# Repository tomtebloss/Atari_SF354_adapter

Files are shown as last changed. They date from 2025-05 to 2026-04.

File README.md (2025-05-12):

<h1 align="center">
PCB for use in an Atari SF354/314 case.
</h1>

<h2 align="center">
Exchange original pcb to be able to read double sided floppy.

---

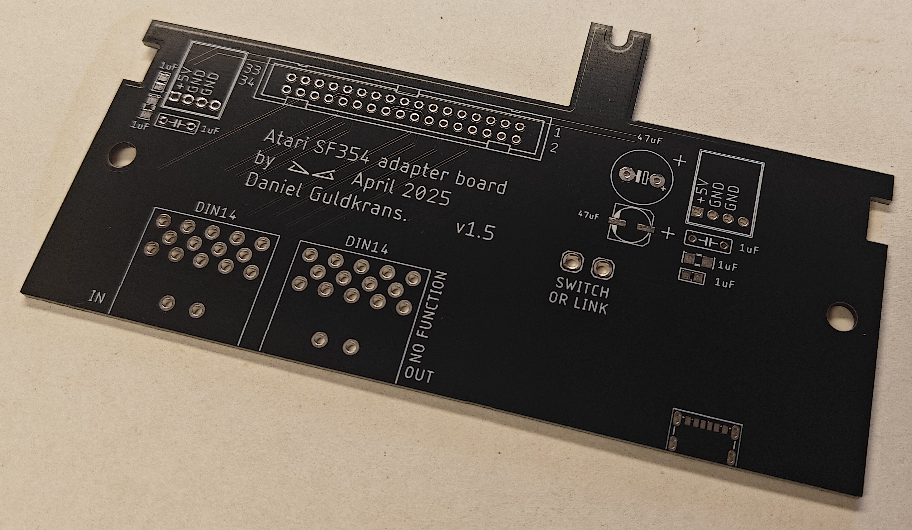
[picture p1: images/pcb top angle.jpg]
new pcb top

</h2>

---

## Background  

I bought an old SF354 case with a broken (dried belt) single sided floppy drive to convert to gotek. The case was the big eject button version. Apparently there is (at least) two different version of the pcb inside. One can be used with double sided drives without modifications. And one with a lot of components on the pcb that needs modifications to work with double sided drives (the one I got). I didn't get any signal cable or power cable/brick with my SF354 so it was no meaning to modify the old pcb since I had to source a power cable for it in that case. So I did a new PCB instead and used USB-C to power it. Only 5V. No 12V is used on this board. 

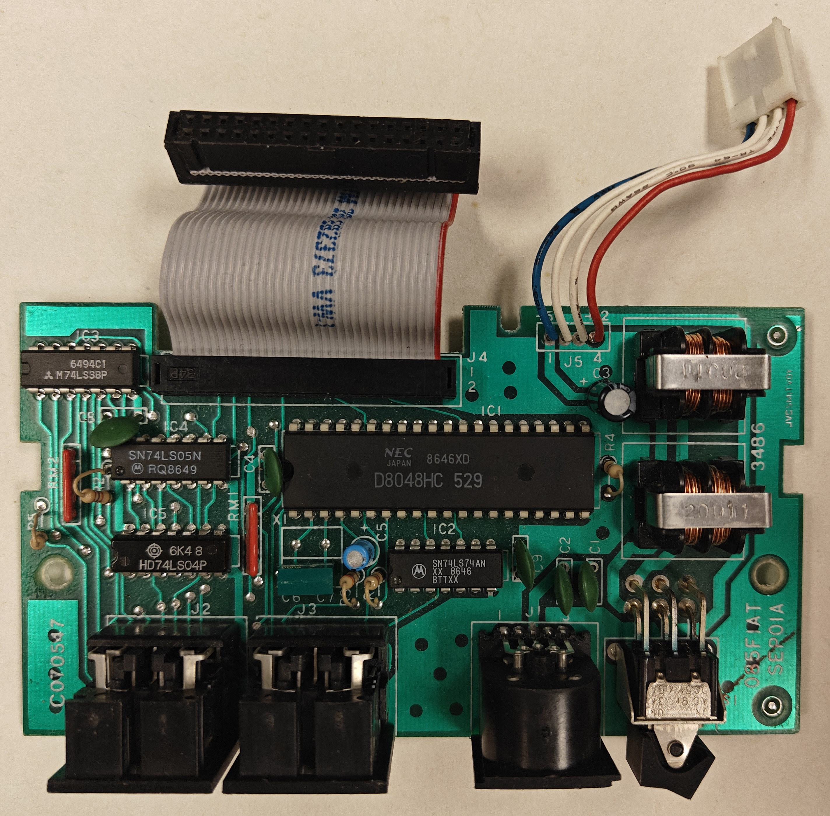
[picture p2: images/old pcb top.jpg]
SF354 original pcb top
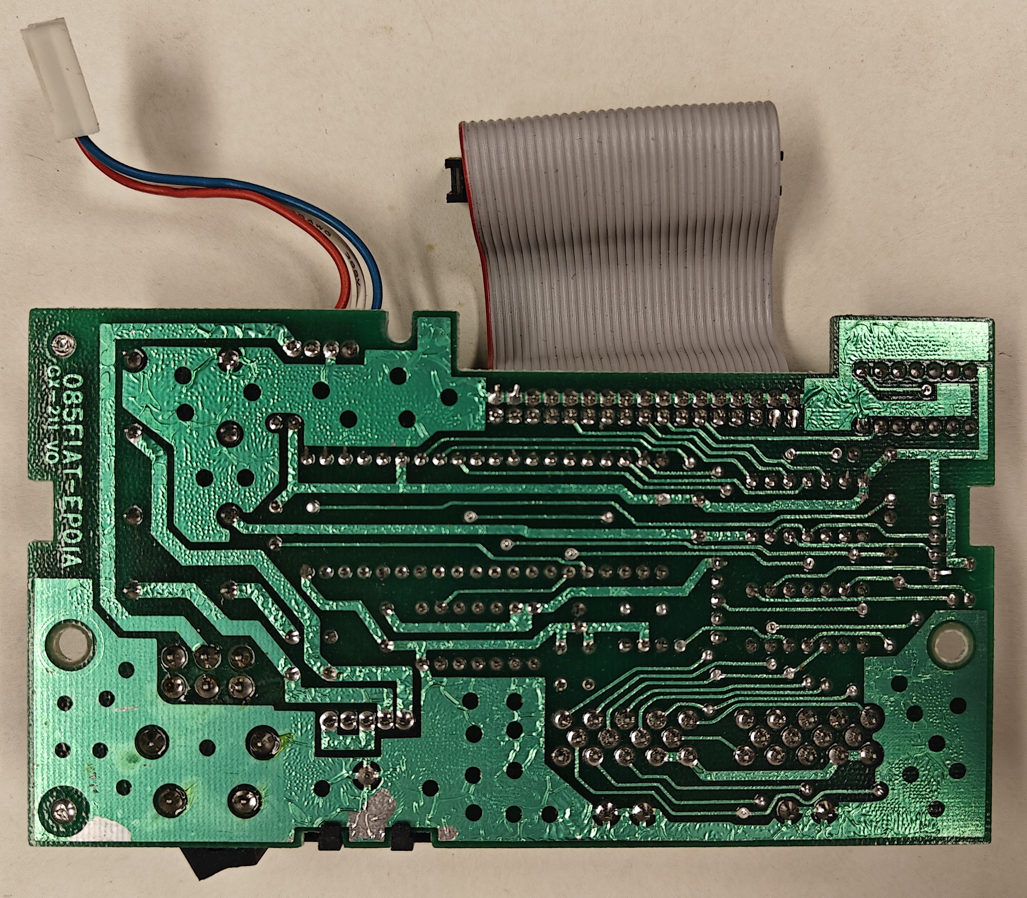
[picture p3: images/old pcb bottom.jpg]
SF354 original pcb bottom


---

## What you will need  

- One Adapter PCB. Order with the [gerber] file "SF354_adapter_pcb_gerber_v1.5.zip" from your favorite PCB manufactory. 
- 1 or 2 pcs of BERG 4 pin floppy power connector (or solder the wires directly to the pcb).
- 1 or 2 pcs of 100nF (0,1uF) 0805 SMD capacitors. This can bew omitted if you want.
- 1 or 2 pcs of 1uF capacitors. Either SMD (1206) or through hole (5,12mm leg pitch).
- One 47uF electrolytic capacitor. Either SMD (size C. 6,3x7,7mm) or through hole (5mm leg pitch).
- 2 pcs of 14 pin DIN connectors. Desolder from old pcb (only one is needed).
- One 34 pin IDC connector. (or solder the wires directly to the pcb).
- One USB-C 6 pin SMD connector. Only used for power.
- One switch (SPDT) or small piece of wire if you don't use it. 
- One Gotek drive or a real disk drive. If Gotek is used you must remove motor on jumper (MO). Only S0 should be jumpered.
- One 3D printed [bracket] for Gotek pcb. 

BOM/partlist can also be found in the [gerber] zip. There is also [PDF] for some parts.

---

## How to

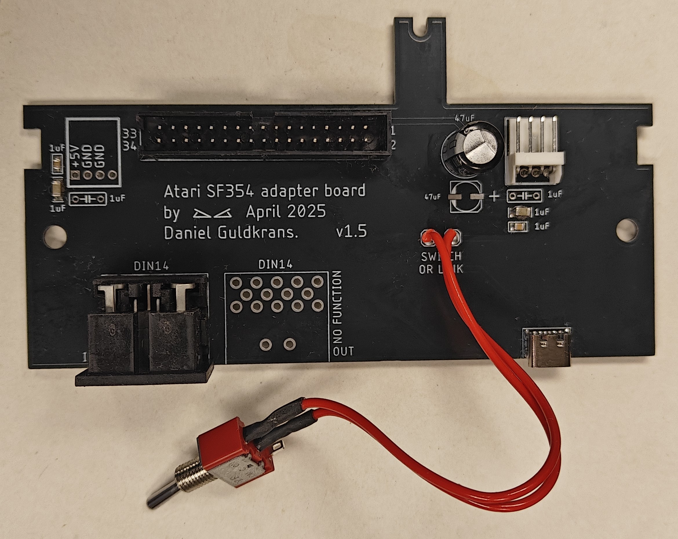
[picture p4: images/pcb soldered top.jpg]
pcb soldered - top side
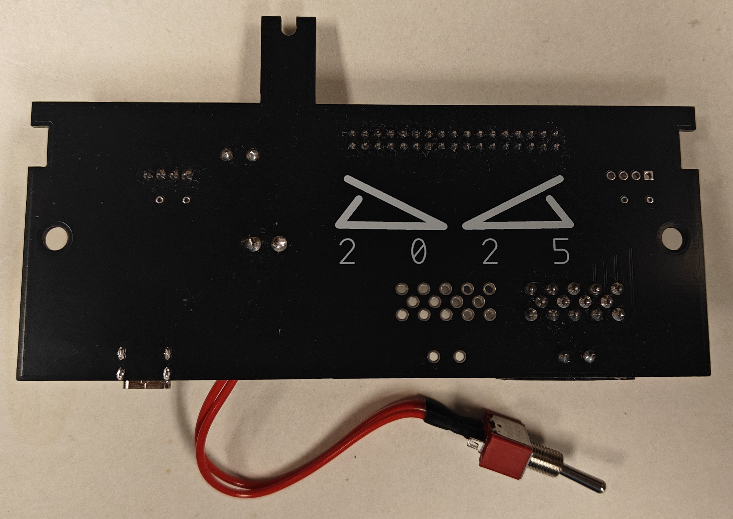
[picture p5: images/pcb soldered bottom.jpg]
pcb soldered - bottom side
| Start by desoldering the two 14 pin DIN connectors from the old pcb. Solder the small capacitors on the new pcb. Choose whatever value you like. I did 1uF on the 1206 SMD ceramic capacitor and 0,1uF on the 0805 cap. Otherwise just do 1uF on the through hole if you don't like surface mount stuff. It doesn't matter really. Choose the placement closest to the connector you are going to use to power your drive. Solder in the USB-C connector. Then the 4 pin BERG connector for power. Choose a spot. Or solder wire directly to the board. You will need a female-female 4-pin power cable if you soldered in a connector on the pcb. Then solder 34 pin IDC connector and then one large 47 uF electrolytic capacitor. Choose through hole or surface mount. Either is fine. Then one or two 14 pin DIN connector. You can solder the ribbon cable directly to the pcb instead of 34 pin connector or you will have to buy a 34-pin ribbon cable for floppy otherwise. |  |
| :--- | :---: |
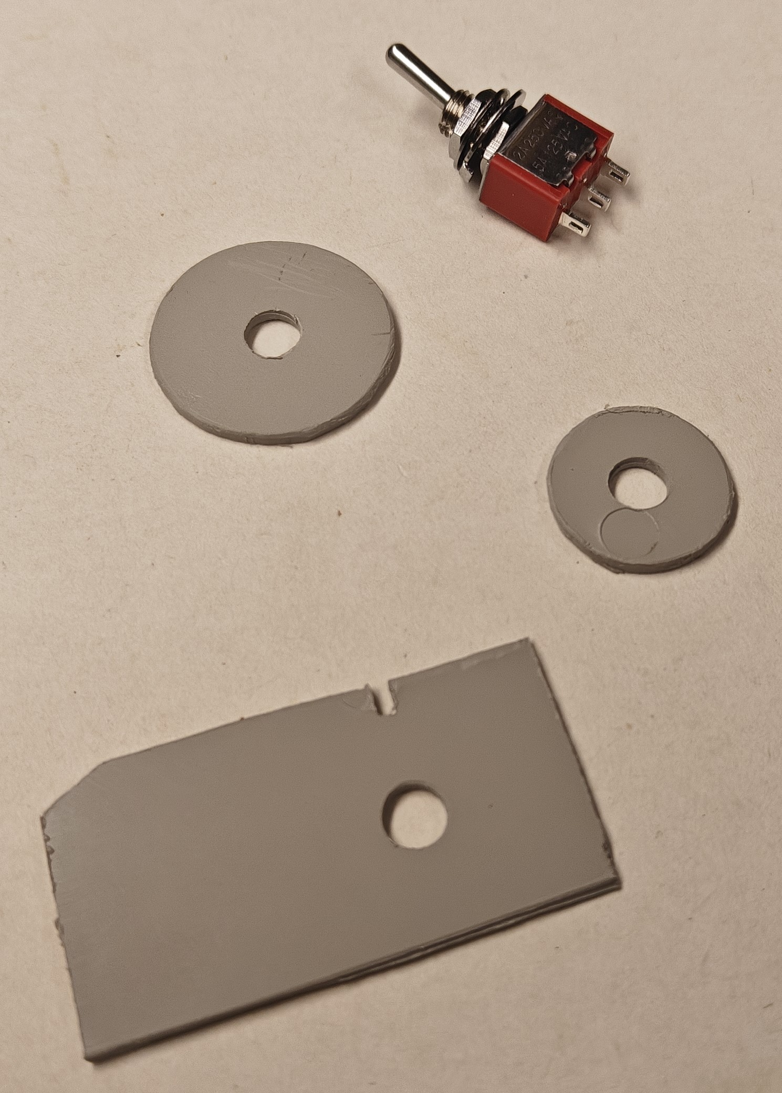
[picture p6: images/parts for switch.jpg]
parts for switch
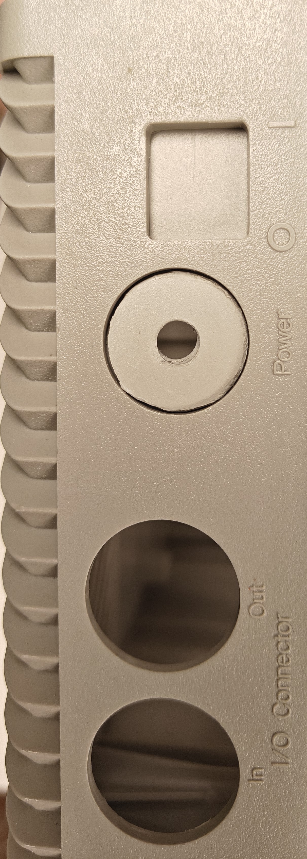
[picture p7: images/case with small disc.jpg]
back of case
| I choose a switch and solder some wires and drilled, saw and filed some parts from the old gotek case. Square part goes inside of case (pic taken before I realized that I needed hole for USB connector). Small disc in the hole then large disc then switch. It will be a sandwich with the case in the middle. If you don't want a switch you have to solder a small wire between the holes that says LINK. Otherwise you will not have power for your drive. |   |
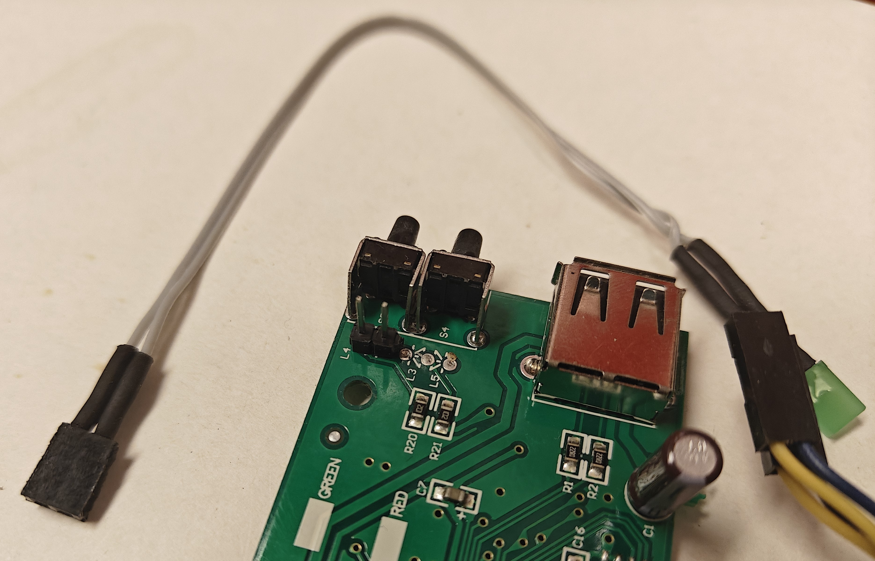
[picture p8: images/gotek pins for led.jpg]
pins on gotek for LED behind button
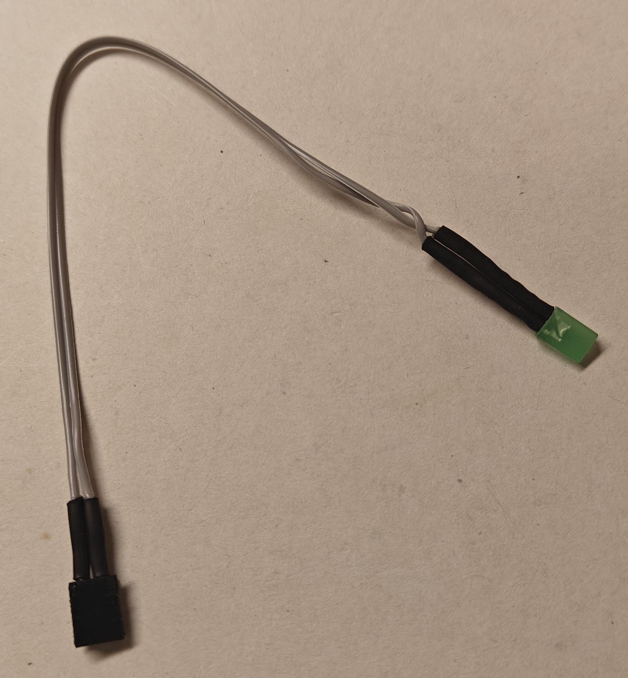
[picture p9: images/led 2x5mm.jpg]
2x5mm LED with wires and heat shrink tube
| The 3D printed front panel has a hole for a 2x5mm LED. I desoldered the round one from the gotek pcb and solderd in some pinheaders instead. I then soldered some wires on a new LED. The orientation can easily be switched if it doesn't lit up. |   |
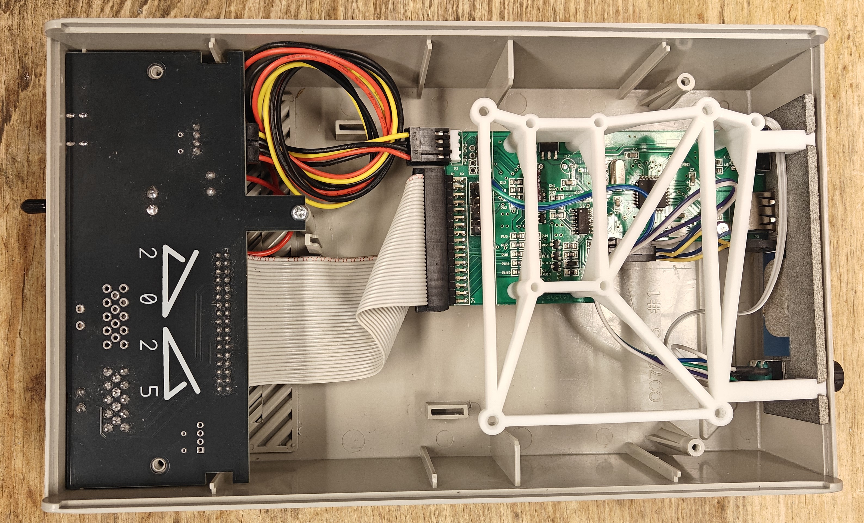
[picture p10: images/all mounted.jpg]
all mounted
| Assemble everything. Fasten with screw. I also used a rotary encoder and a buzzer on my gotek. You can use whatever mod you like on yours. Check flashfloppy [hardware mods]. |  |
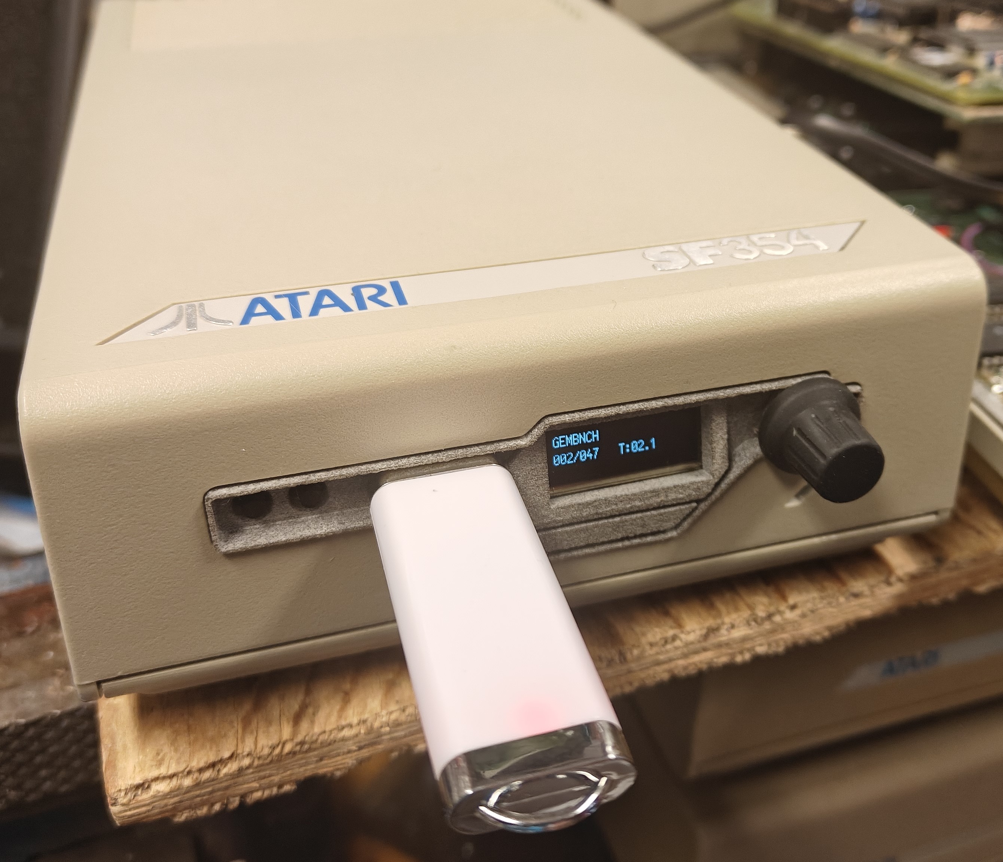
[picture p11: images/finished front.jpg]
Assembled front side
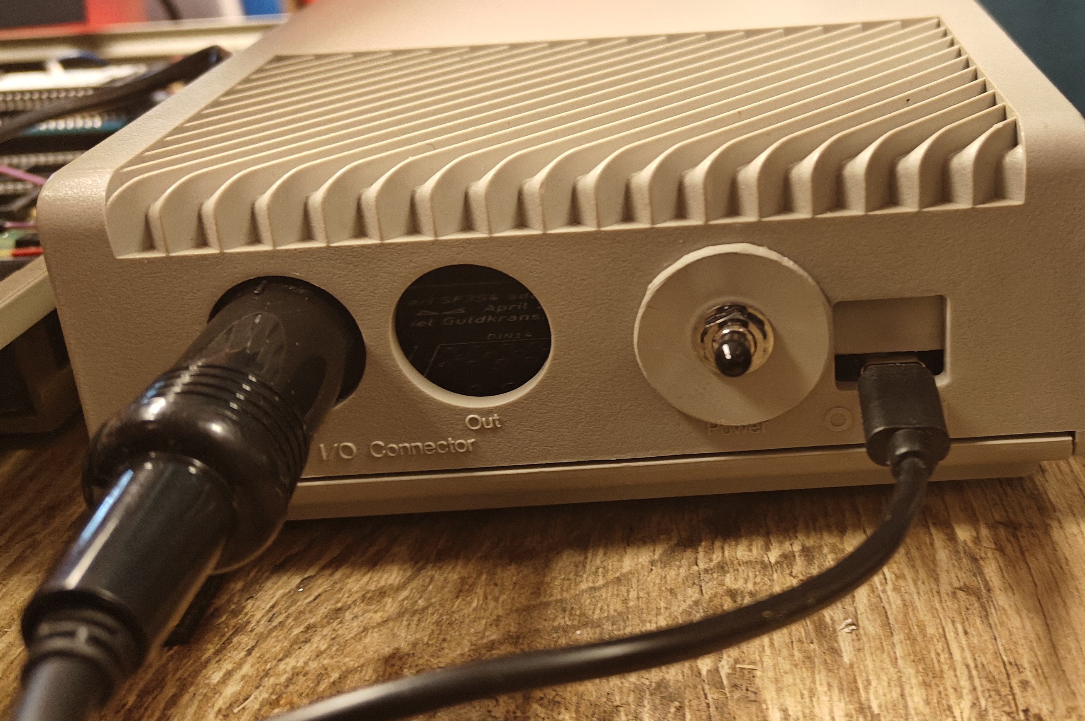
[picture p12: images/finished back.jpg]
Assembled back side
|  |  |

---

## Testing

I tested this with a Mega ST 1 upgraded to 4Mb and with a TSENG ET4000AX graphics card. I also used 256Kb roms (EmuTOS v1.3 and TOS v2.06). I used two Goteks in the picture below but I also tested with two real floppy disk drives. But it should work with any double sided drive and system I hope. Do ***NOT*** use MO jumper on the Gotek otherwise it will not work! Only use S0 jumper. I can't remember what USB charger I used. 1A should be fine.

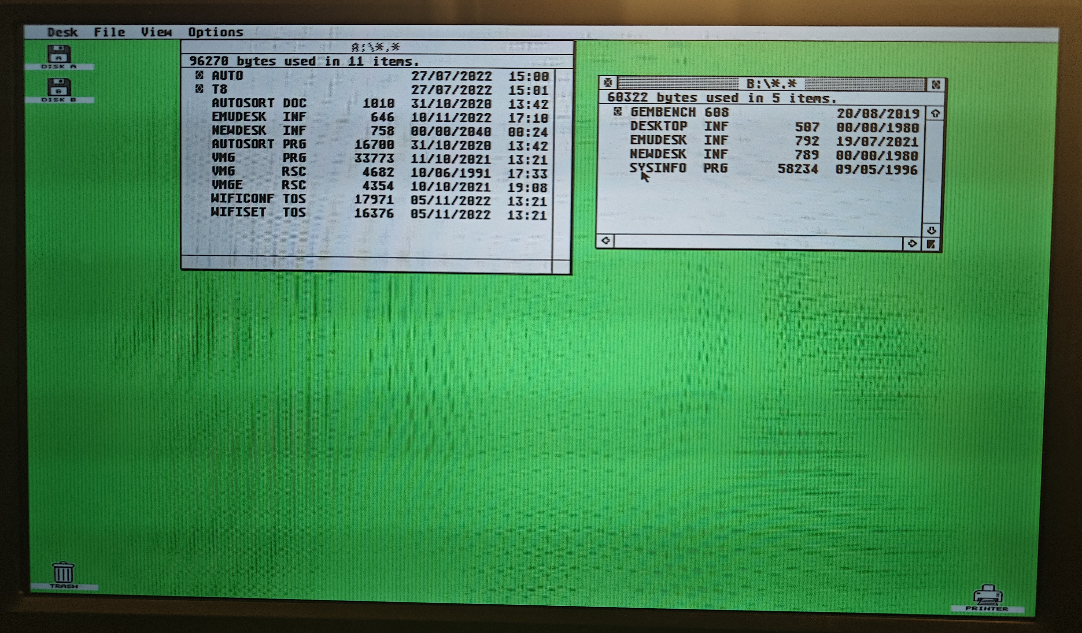
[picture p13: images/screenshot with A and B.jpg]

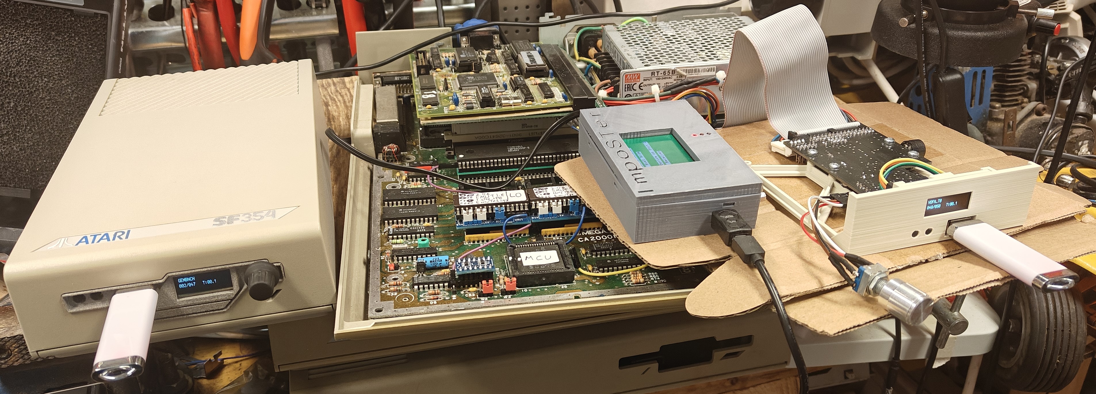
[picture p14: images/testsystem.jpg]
testsystem


---

PCB made by Daniel Guldkrans aka DoG in Eagle April 2025.

[PDF]: pdf/
[gerber]: gerber/SF354_adapter_pcb_gerber_v1.5.zip
[bracket]: https://www.thingiverse.com/thing:6960806
[hardware mods]: https://github.com/keirf/flashfloppy/wiki/Hardware-Mods

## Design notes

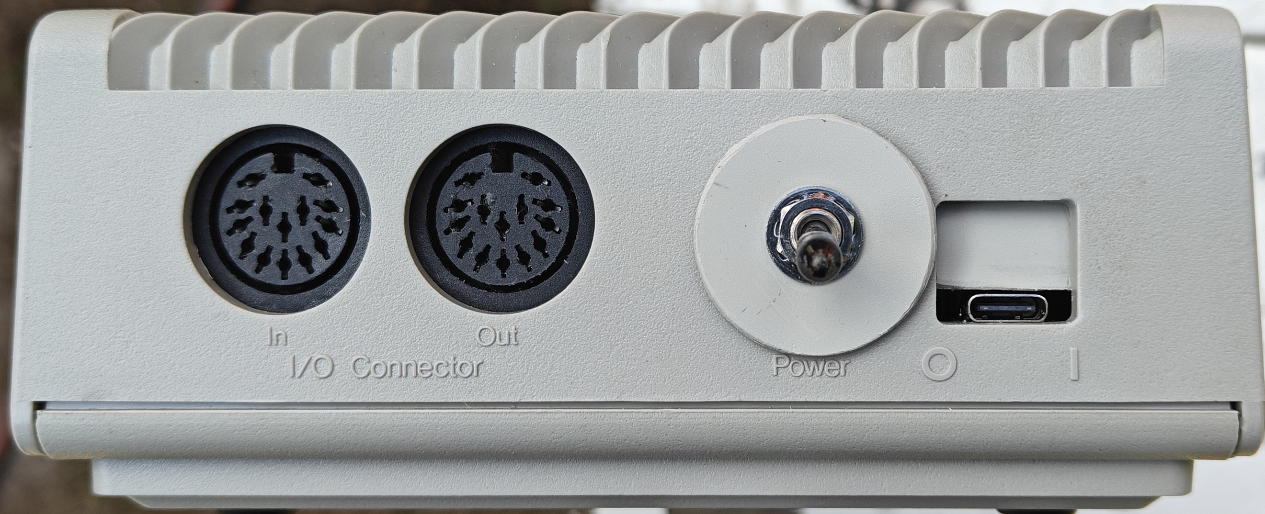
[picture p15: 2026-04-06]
images/Updated case pic back.jpg

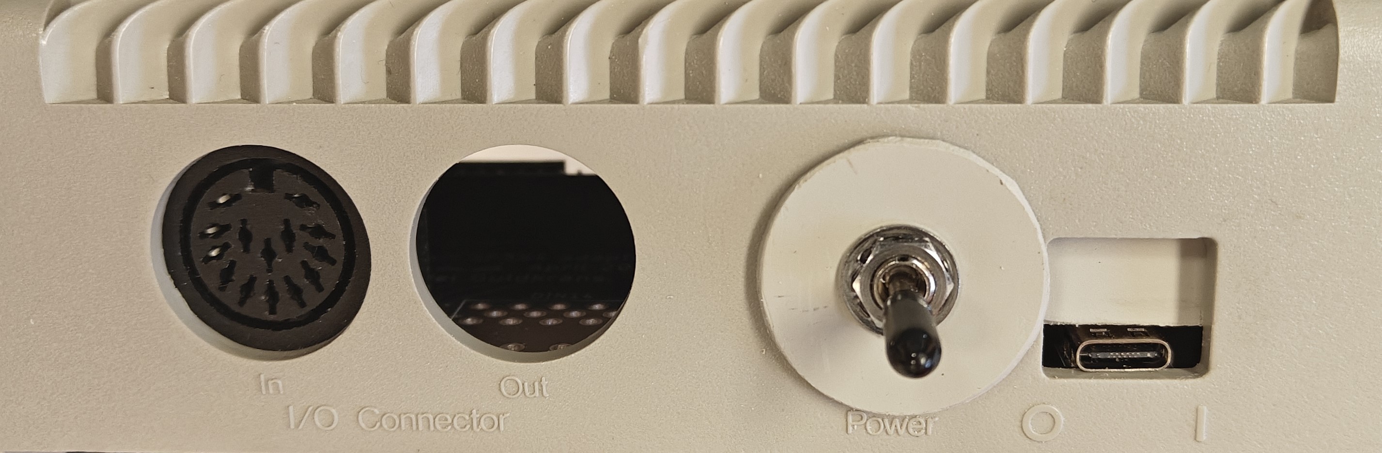
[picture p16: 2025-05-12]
images/housing back.jpg

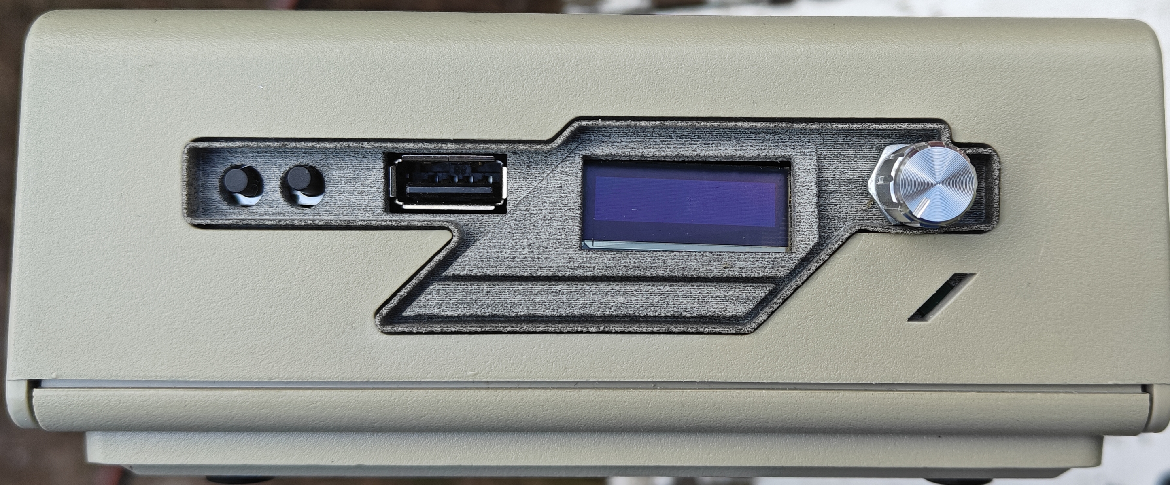
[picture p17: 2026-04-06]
images/Updated case pic front.jpg

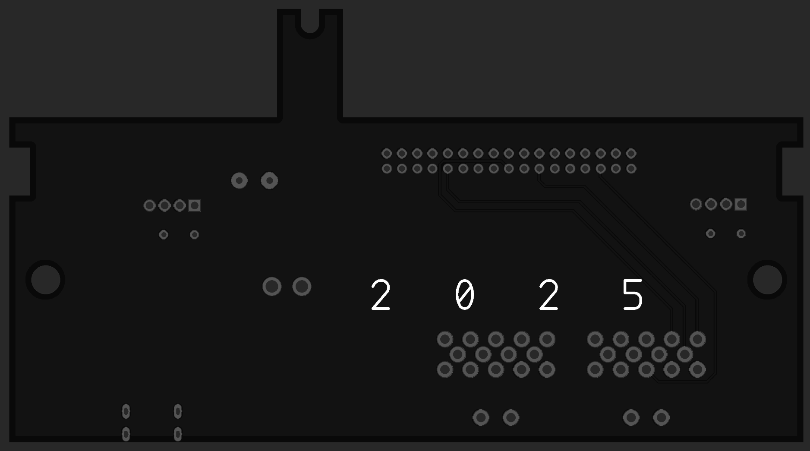
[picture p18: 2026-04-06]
images/PCB_bottom_v1.5_EAGLE_9.6.2.png

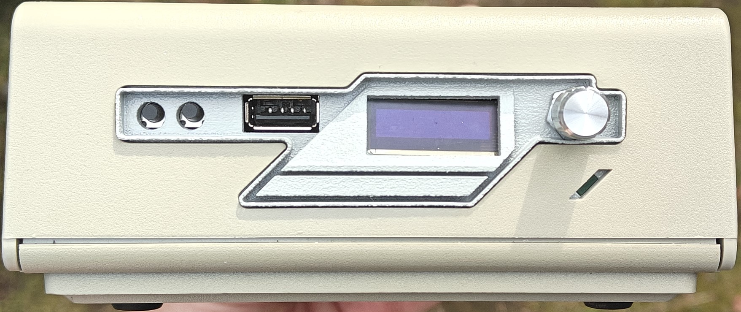
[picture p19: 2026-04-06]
images/painted front and green activity LED.jpg

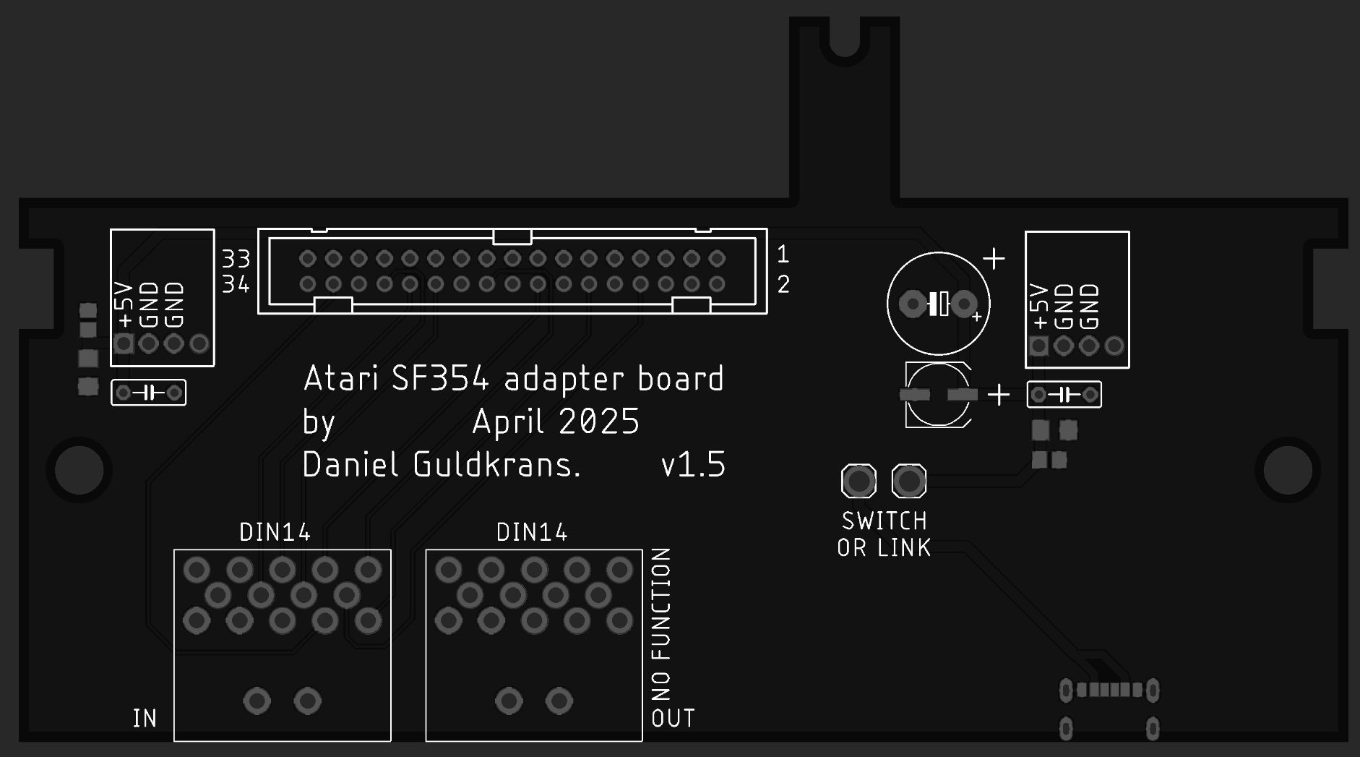
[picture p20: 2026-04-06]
images/PCB_top_v1.5_EAGLE_9.6.2.png

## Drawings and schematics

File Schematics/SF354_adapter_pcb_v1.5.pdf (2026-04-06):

SWITCH | SF354 Adapter board by Daniel Guldkrans

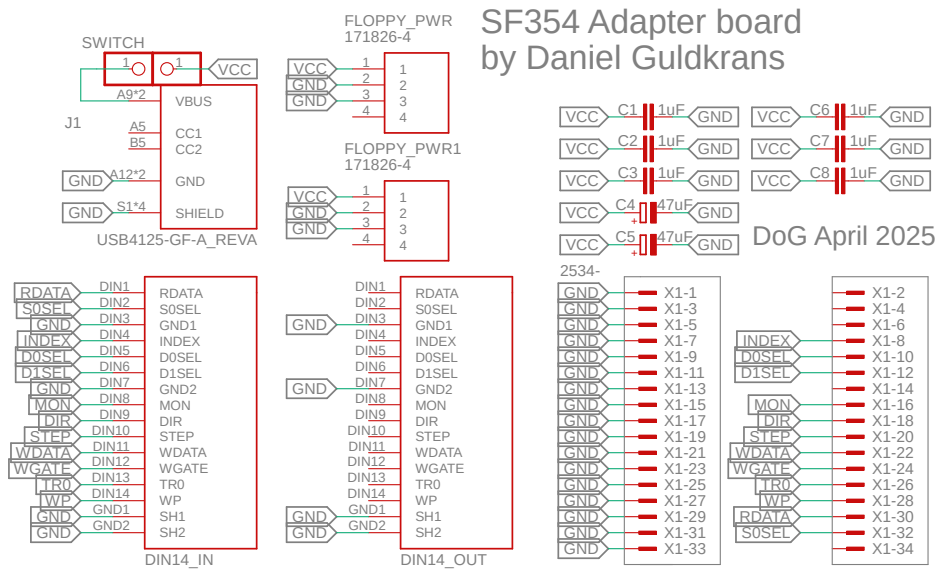
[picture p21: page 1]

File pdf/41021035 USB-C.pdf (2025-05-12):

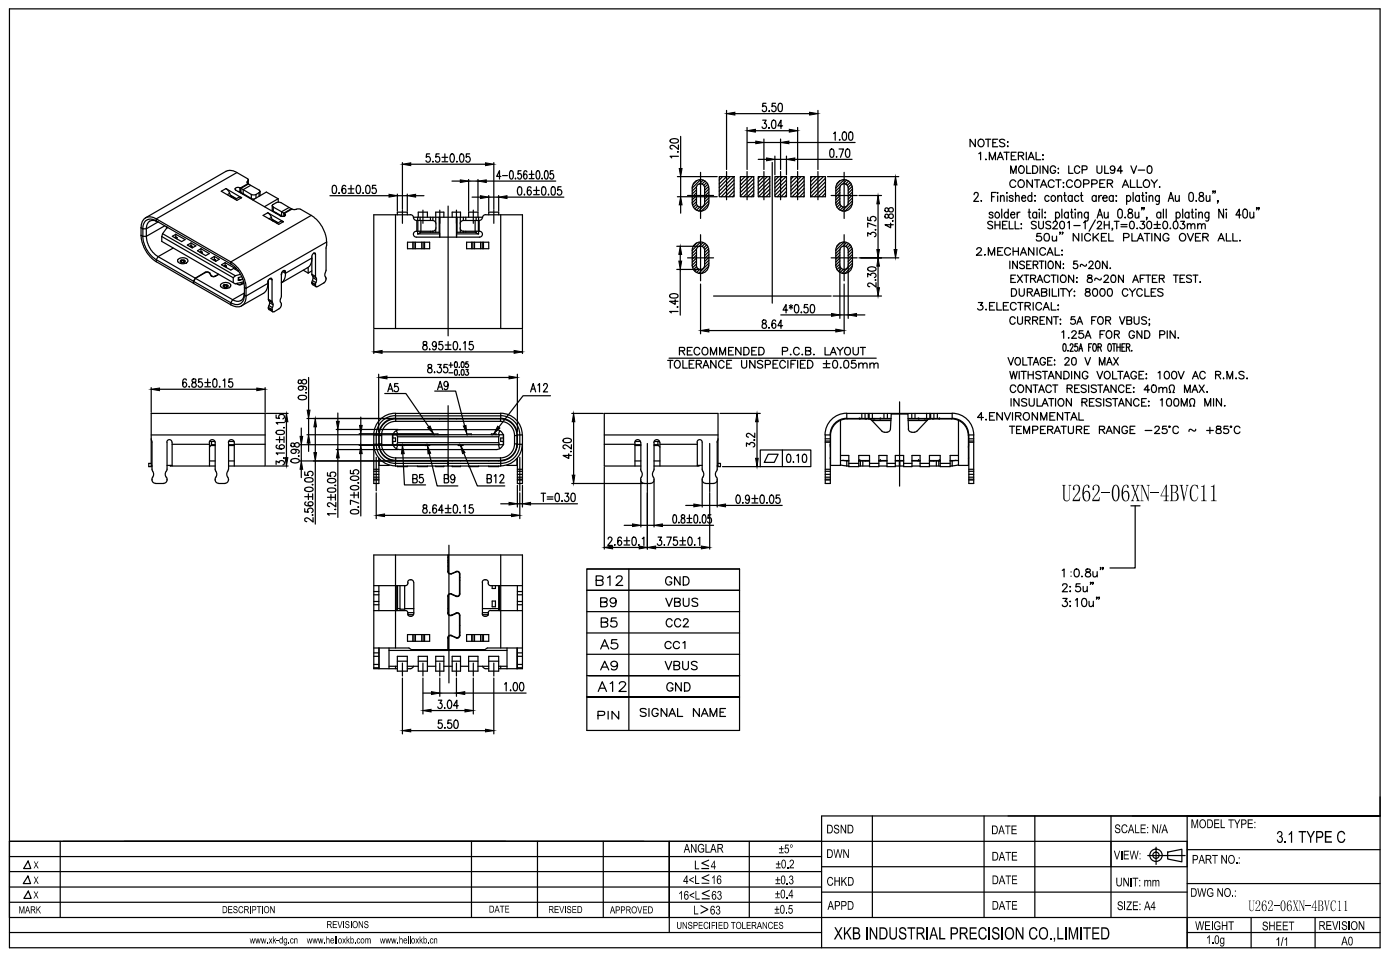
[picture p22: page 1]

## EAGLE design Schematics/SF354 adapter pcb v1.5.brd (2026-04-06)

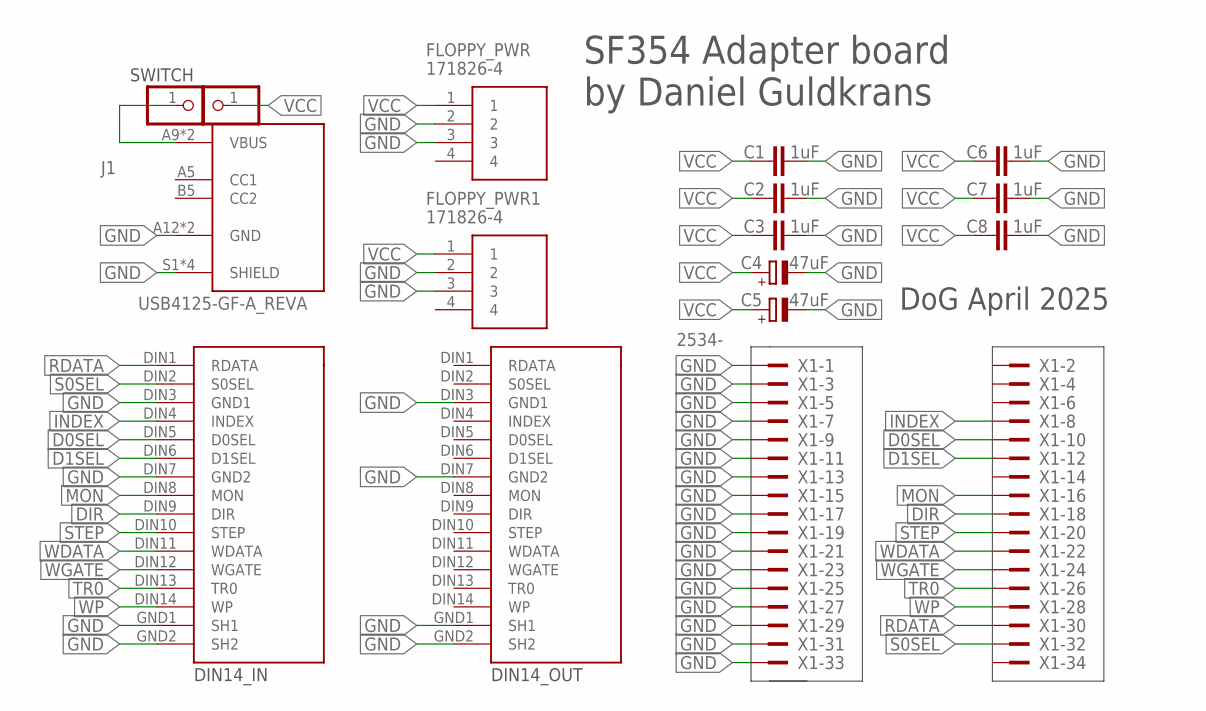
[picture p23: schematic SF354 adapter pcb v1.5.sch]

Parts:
C1, C6: 1uF; C1206
C2, C7: 1uF; C0805
C3, C8: 1uF; C050-025X075
C4: 47uF; UD-6,3X7,7_NICHICON
C5: 47uF; E5-10,5
FLOPPY_PWR, FLOPPY_PWR1: 171826-4; SHDRRA4W69P0X250_1X4_1000X1350
J1: USB4125-GF-A_REVA; GCT_USB4125-GF-A_REVA
JP1, JP2: PINHD-1X11X01_BH; 1X01_BH
U$1, U$2: DIN14
X1: 2534-; PAK100/2500-34

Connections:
D0SEL: U$1.DIN5 (D0SEL), X1.10
D1SEL: U$1.DIN6 (D1SEL), X1.12
DIR: U$1.DIN9 (DIR), X1.18
GND: C1.2, C2.2, C3.2, C4.-, C5.-, C6.2, C7.2, C8.2, FLOPPY_PWR.2, FLOPPY_PWR.3, FLOPPY_PWR1.2, FLOPPY_PWR1.3, J1.A12 (GND), J1.B12 (GND), J1.S1 (SHIELD), J1.S2 (SHIELD), J1.S3 (SHIELD), J1.S4 (SHIELD), U$1.DIN3 (GND1), U$1.DIN7 (GND2), U$1.GND1 (SH1), U$1.GND2 (SH2), U$2.DIN3 (GND1), U$2.DIN7 (GND2), U$2.GND1 (SH1), U$2.GND2 (SH2), X1.1, X1.3, X1.5, X1.7, X1.9, X1.11, X1.13, X1.15, X1.17, X1.19, X1.21, X1.23, X1.25, X1.27, X1.29, X1.31, X1.33
INDEX: U$1.DIN4 (INDEX), X1.8
MON: U$1.DIN8 (MON), X1.16
unnamed: J1.A9 (VBUS), J1.B9 (VBUS), JP2.1
RDATA: U$1.DIN1 (RDATA), X1.30
S0SEL: U$1.DIN2 (S0SEL), X1.32
STEP: U$1.DIN10 (STEP), X1.20
TR0: U$1.DIN13 (TR0), X1.26
VCC: C1.1, C2.1, C3.1, C4.+, C5.+, C6.1, C7.1, C8.1, FLOPPY_PWR.1, FLOPPY_PWR1.1, JP1.1
WDATA: U$1.DIN11 (WDATA), X1.22
WGATE: U$1.DIN12 (WGATE), X1.24
WP: U$1.DIN14 (WP), X1.28

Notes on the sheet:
DIN14_IN
DIN14_OUT
SWITCH
SF354 Adapter board by Daniel Guldkrans
DoG April 2025

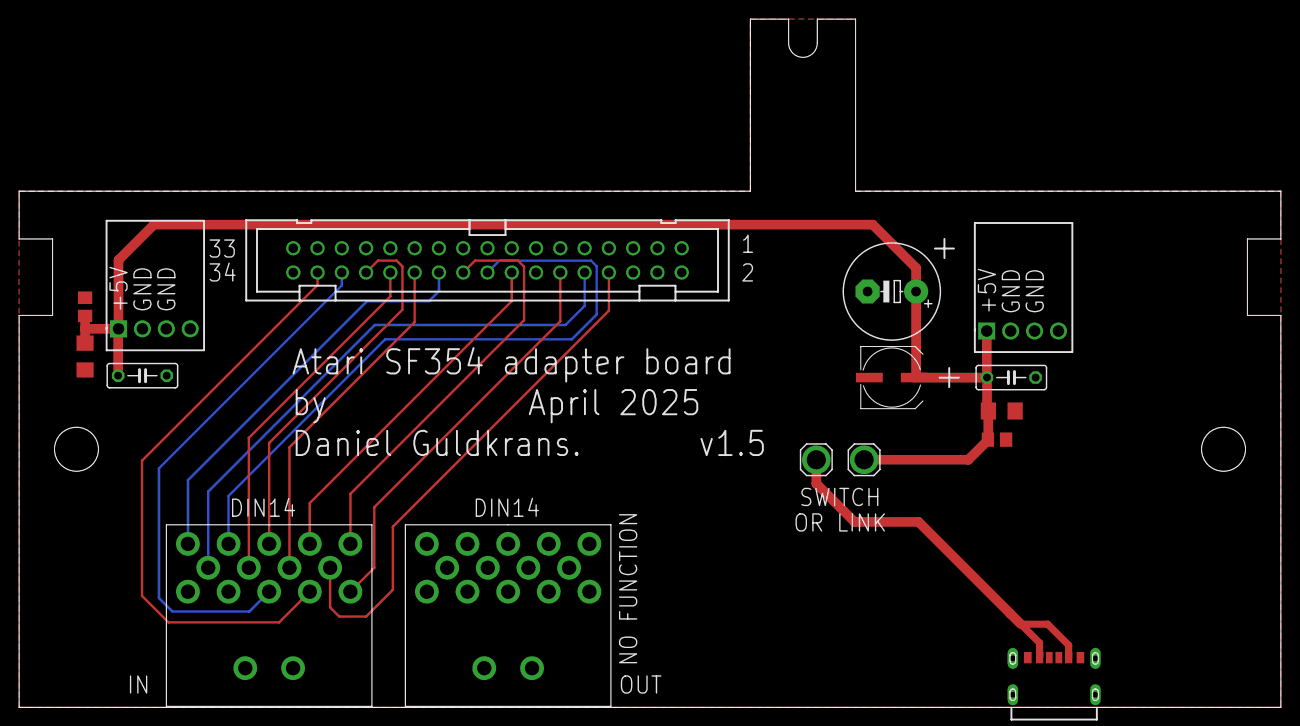
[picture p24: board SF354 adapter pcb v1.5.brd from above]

Board: 2 copper layers, 132.0 x 72.0 mm, 16 parts (0 on the bottom side), 15 nets.

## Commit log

2025-05-12 gerber files for ordering pcb
2026-04-06 Eagle v9.6.2 files
    [SF354 adapter pcb v1.5.brd, SF354 adapter pcb v1.5.sch]
2026-04-06 New knob, painted front, back covered
    New samller rotary knob, painted front, 2 soldered DIN14
2026-04-06 Painted front and activity LED
